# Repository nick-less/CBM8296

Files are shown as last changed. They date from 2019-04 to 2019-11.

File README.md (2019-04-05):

The files I used to repair my Commodore 8296, maybe someone finds this useful. 
Its not my own work I just combined the XC9536 PLA from http://www.nightfallcrew.com/18/11/2009/xilink-cpld-xc9536-replacement-pla-for-commodore-64/
with the Equations from http://www.zimmers.net/anonftp/pub/cbm/firmware/computers/pet/8296/index.html

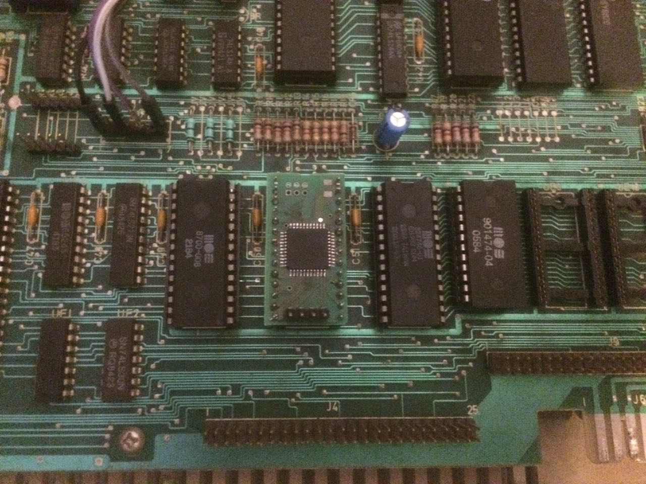
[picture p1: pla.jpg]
PLA
This is how it looks

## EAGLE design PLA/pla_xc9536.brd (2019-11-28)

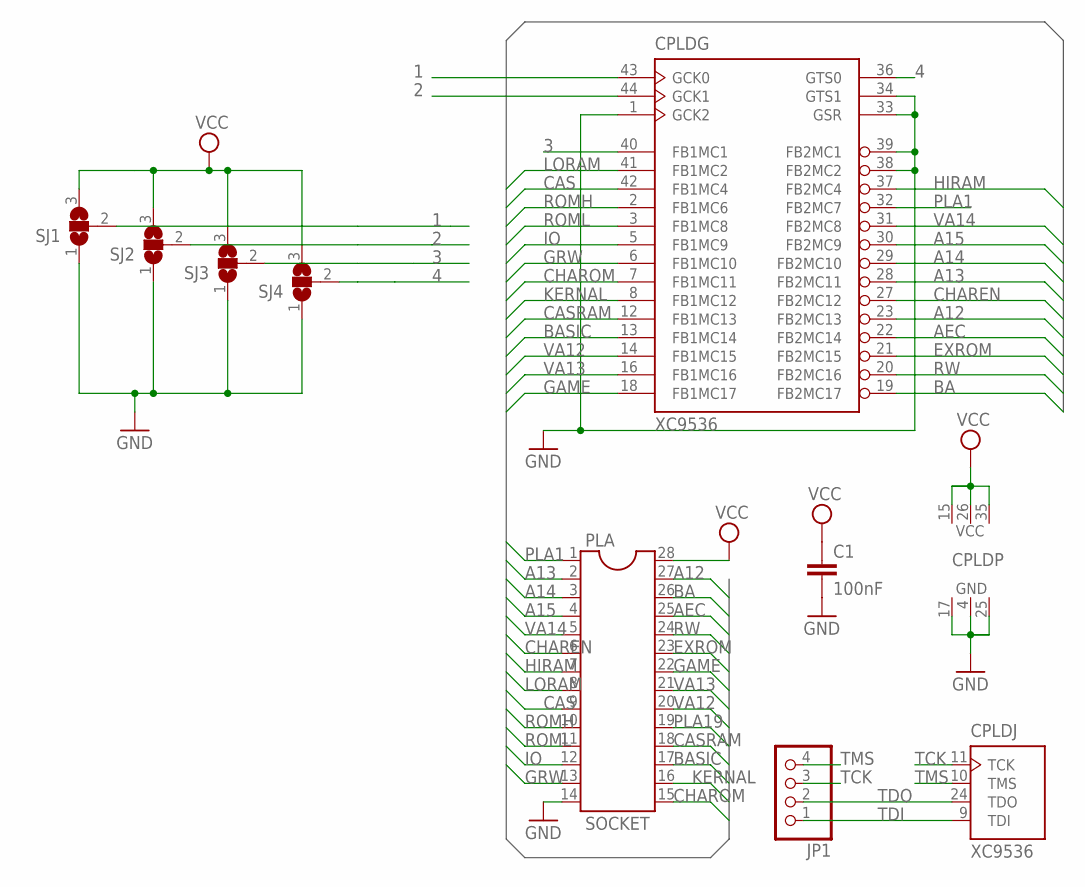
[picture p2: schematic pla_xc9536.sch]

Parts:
C1: 100nF; C1206K
CPLD: XC9536; VQ44
JP1: PINHD-1X4; 1X04
PLA: SOCKET; DIL28-6-ROUND
SJ1, SJ2, SJ3, SJ4: SJ2W; SJ_2

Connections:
1: CPLD.43 (GCK0), SJ1.2
2: CPLD.44 (GCK1), SJ2.2
3: CPLD.40 (FB1MC1), SJ3.2
4: CPLD.36 (GTS0), SJ4.2
A12: CPLD.23 (FB2MC13), PLA.27
A13: CPLD.28 (FB2MC11), PLA.2
A14: CPLD.29 (FB2MC10), PLA.3
A15: CPLD.30 (FB2MC9), PLA.4
AEC: CPLD.22 (FB2MC14), PLA.25
BA: CPLD.19 (FB2MC17), PLA.26
BASIC: CPLD.13 (FB1MC14), PLA.17
CAS: CPLD.42 (FB1MC4), PLA.9
CASRAM: CPLD.12 (FB1MC13), PLA.18
CHAREN: CPLD.27 (FB2MC12), PLA.6
CHAROM: CPLD.7 (FB1MC11), PLA.15
EXROM: CPLD.21 (FB2MC15), PLA.23
GAME: CPLD.18 (FB1MC17), PLA.22
GND: C1.2, CPLD.1 (GCK2), CPLD.4 (GND), CPLD.17 (GND), CPLD.25 (GND), CPLD.33 (GSR), CPLD.34 (GTS1), CPLD.38 (FB2MC2), CPLD.39 (FB2MC1), PLA.14, SJ1.1, SJ2.1, SJ3.1, SJ4.1
GRW: CPLD.6 (FB1MC10), PLA.13
HIRAM: CPLD.37 (FB2MC4), PLA.7
IO: CPLD.5 (FB1MC9), PLA.12
KERNAL: CPLD.8 (FB1MC12), PLA.16
LORAM: CPLD.41 (FB1MC2), PLA.8
PLA1: CPLD.32 (FB2MC7), PLA.1
PLA19: PLA.19
ROMH: CPLD.2 (FB1MC6), PLA.10
ROML: CPLD.3 (FB1MC8), PLA.11
RW: CPLD.20 (FB2MC16), PLA.24
TCK: CPLD.11 (TCK), JP1.3
TDI: CPLD.9 (TDI), JP1.1
TDO: CPLD.24 (TDO), JP1.2
TMS: CPLD.10 (TMS), JP1.4
VA12: CPLD.14 (FB1MC15), PLA.20
VA13: CPLD.16 (FB1MC16), PLA.21
VA14: CPLD.31 (FB2MC8), PLA.5
VCC: C1.1, CPLD.15 (VCC), CPLD.26 (VCC), CPLD.35 (VCC), PLA.28, SJ1.3, SJ2.3, SJ3.3, SJ4.3

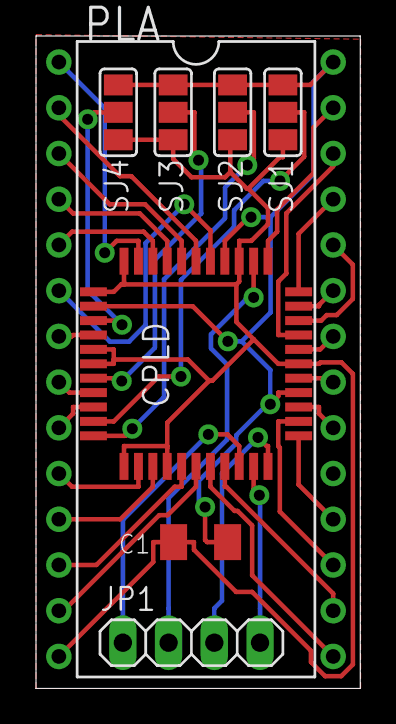
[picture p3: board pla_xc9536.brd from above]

Board: 2 copper layers, 18.0 x 36.2 mm, 8 parts (0 on the bottom side), 35 nets.

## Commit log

2017-10-26 files used to create a working UC6 PLA for the 8296
    [pla_xc9536.brd, pla_xc9536.sch]
2019-11-28 updated schematic to remove floating pins
    [pla_xc9536.brd, pla_xc9536.sch]
